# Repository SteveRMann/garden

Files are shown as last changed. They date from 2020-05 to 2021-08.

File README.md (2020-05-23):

# GardenProject
This project is for the solar-powered Wemos D1 mini with a DS18B20 temperature sensor and a Capacitive Moisture sensor.

---------------
Here is a project by Nick Gammon that uses a supercap instead of a battery.
https://www.gammon.com.au/forum/?id=12821

---------------
The publish functions expect char[] types to be passed in rather than Strings.
You need to use the String.toCharArray() function to convert your strings to the necessary type.

char charBuf[50];
stringOne.toCharArray(charBuf, 50)
myString.toCharArray(buf, len)

----------------------
For future reference:
#include <IPAddress.h>
IPAddress ipAddress(192, 168, 0, 1);  

--------

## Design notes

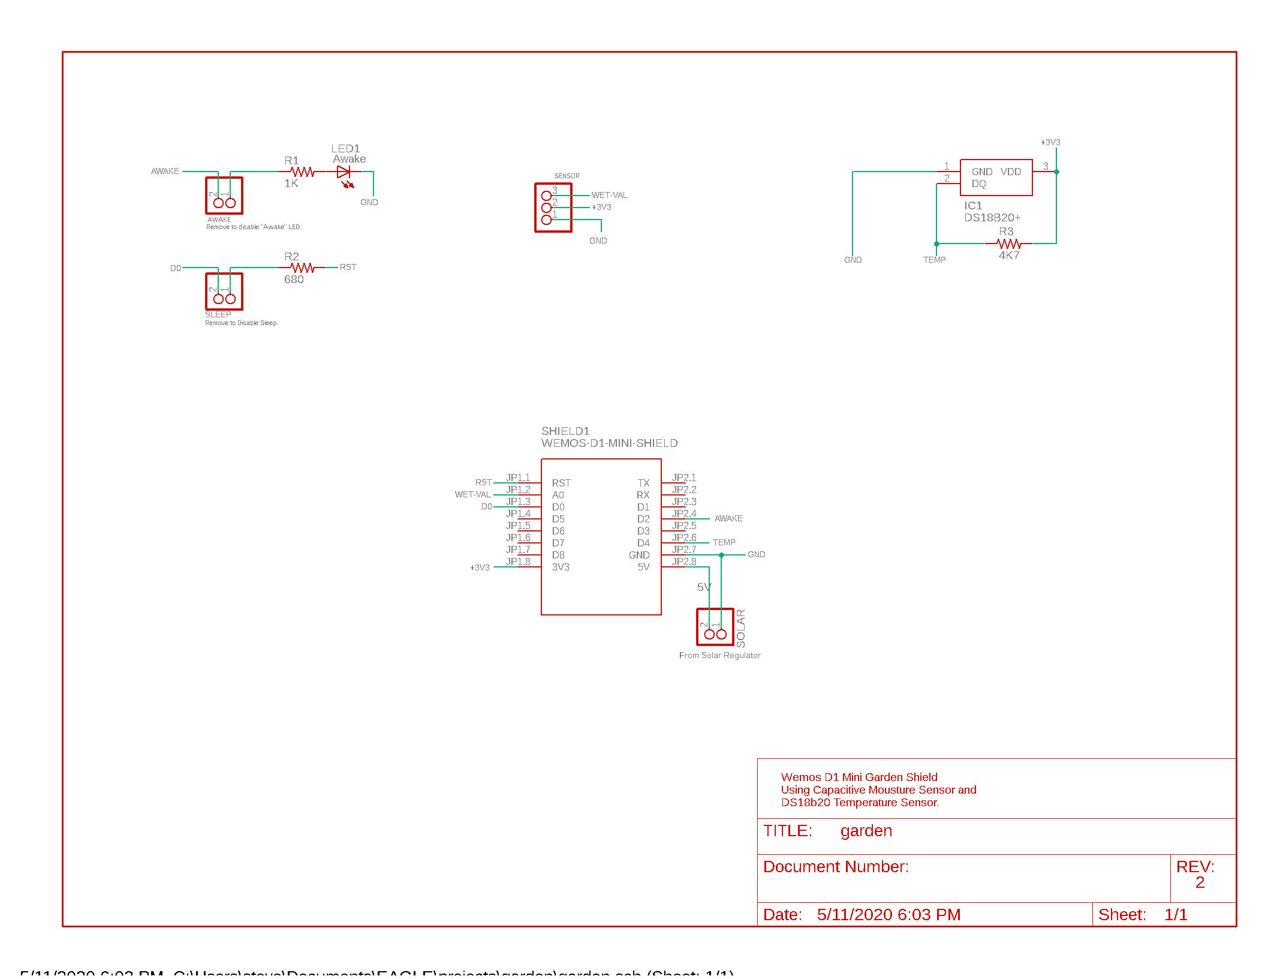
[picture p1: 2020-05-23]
Schematic.jpg

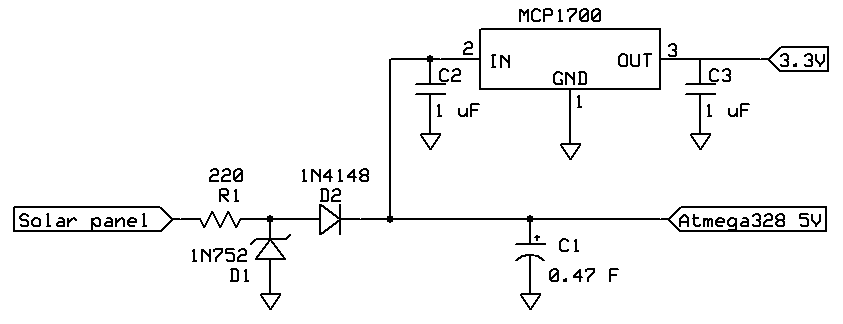
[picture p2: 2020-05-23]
Gammon Solar panel schematic.png

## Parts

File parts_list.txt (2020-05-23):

Partlist

Exported from garden.sch at 4/30/2020 11:53 AM

EAGLE Version 9.3.2 Copyright (c) 1988-2019 Autodesk, Inc.

Assembly variant: 

Part            Value                          Device               Package              Library        Sheet

AWAKE           Remove to disable "Awake" LED. PINHD-1X2            1X02                 DC_LOAD_AU     1
IC1             DS18B20+                       DS18B20+             TO-92                SamacSys_Parts 1
LED1            Awake                          LED3MM               LED3MM               adafruit       1
MOISTURE_SENSOR Moisture Sensor                PINHD-1X3/90         1X03/90              pinhead        1
R1              1K                             R-US_0207/9          0207/9               adafruit       1
R2              680                            R-US_0207/9          0207/9               adafruit       1
R3              4K7                            R-US_0207/9          0207/9               adafruit       1
SHIELD1         WEMOS-D1-MINI-SHIELD           WEMOS-D1-MINI-SHIELD WEMOS-D1-MINI-SHIELD diy-modules    1
SLEEP           Remove to Disable Sleep.       PINHD-1X2            1X02                 DC_LOAD_AU     1
SOLAR           From Solar Regulator           PINHD-1X2/90         1X02/90              DC_LOAD_AU     1
T1              2N2222                         2N2222               TO92-EBC-OVAL        adafruit       1

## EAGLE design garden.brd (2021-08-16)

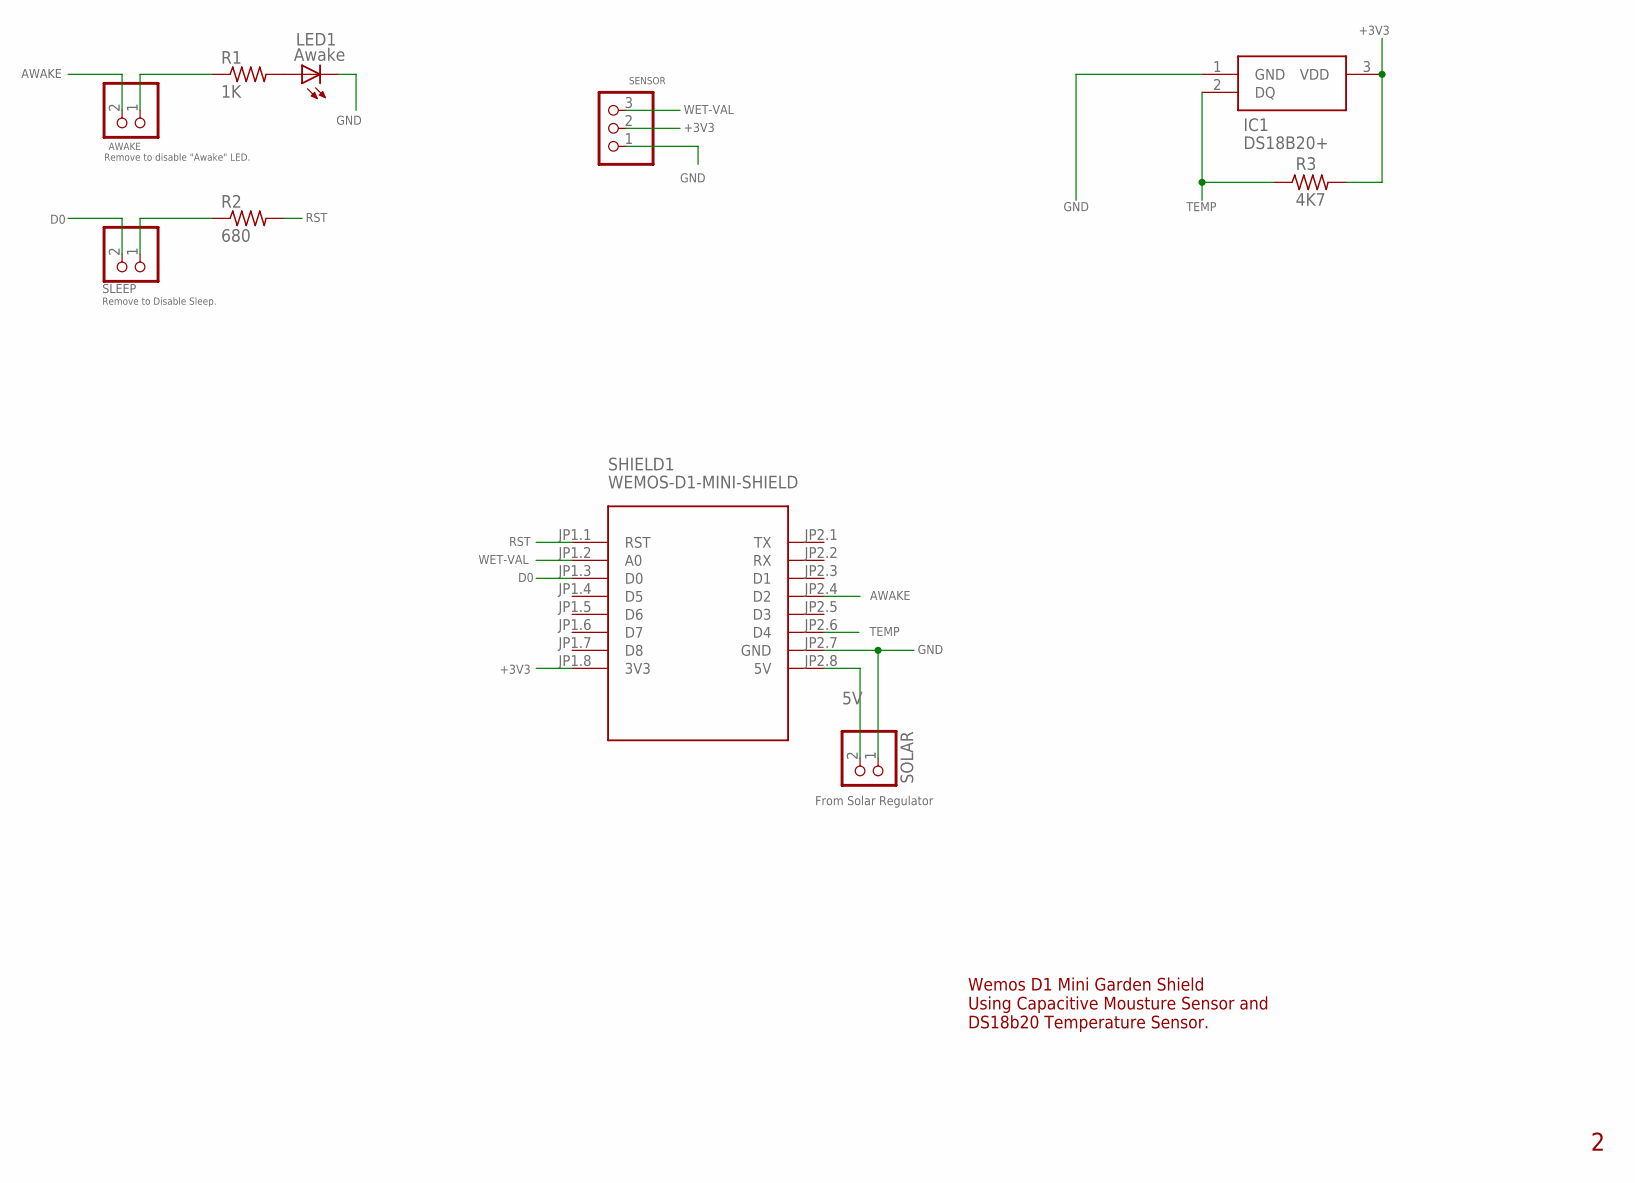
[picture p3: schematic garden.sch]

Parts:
AWAKE: Remove to disable "Awake" LED.; 1X02
IC1: DS18B20+; TO-92
LED1: Awake; LED3MM
R1: 1K; 0207/9
R2: 680; 0207/9
R3: 4K7; 0207/9
SENSOR: Moisture Sensor; 1X03/90
SHIELD1: WEMOS-D1-MINI-SHIELD
SLEEP: Remove to Disable Sleep.; 1X02
SOLAR: From Solar Regulator; 1X02/90

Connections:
5V: SHIELD1.JP2.8 (5V), SOLAR.2
+3V3: IC1.3 (VDD), R3.2, SENSOR.2, SHIELD1.JP1.8 (3V3)
AWAKE: AWAKE.2, SHIELD1.JP2.4 (D2)
D0: SHIELD1.JP1.3 (D0), SLEEP.2
GND: IC1.1 (GND), LED1.K (C), SENSOR.1, SHIELD1.JP2.7 (GND), SOLAR.1
unnamed: LED1.A, R1.2
unnamed: AWAKE.1, R1.1
unnamed: R2.1, SLEEP.1
RST: R2.2, SHIELD1.JP1.1 (RST)
TEMP: IC1.2 (DQ), R3.1, SHIELD1.JP2.6 (D4)
WET-VAL: SENSOR.3, SHIELD1.JP1.2 (A0)

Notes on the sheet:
Wemos D1 Mini Garden Shield Using Capacitive Mousture Sensor and DS18b20 Temperature Sensor.

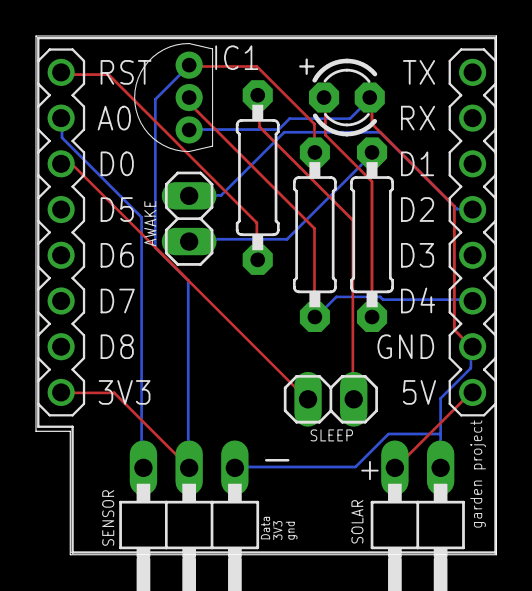
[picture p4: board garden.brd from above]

Board: 2 copper layers, 25.6 x 28.8 mm, 10 parts (0 on the bottom side), 11 nets.

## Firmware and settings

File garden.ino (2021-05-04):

#define sketchName "garden.ino, V2.1"

/*
   Forked from GardenProject
   Removed sleep.
   V2.1 5/4/21 Changed period to 5 minutes

   IDE:
     Board: Lolin(Wemos) D1 R2 & Mini

   Reference:
   http://www.esp8266learning.com/wemos-mini-ds18b20-temperature-sensor-example.php#codesyntax_3

*/


#include <OneWire.h>            // Driver for DS18X Temperature Sensors.
#include <ESP8266WiFi.h>        // Connect (and reconnect) an ESP8266 to the a WiFi network.
#include <PubSubClient.h>       // connect to a MQTT broker and publish/subscribe messages in topics.
#include <ArduinoOTA.h>
#include <ArduinoJson.h>

#ifndef Kaywinnet
#include "C:\Users\steve\Documents\Arduino\libraries\Kaywinnet\Kaywinnet.h"  // WiFi credentials
#endif


// ****************************** Globals  ******************************
#define NODENAME "garden"                         //Must be unique on the net.
const char *connectName =  NODENAME "garden";     //Must be unique on the network

//Probe Calibration
int dry = 457;                  //Dry sensor
int wet = 811;                  //Wet sensor


#define hostPrefix NODENAME     // For setupWiFi()
char macBuffer[24];             // Holds the last three digits of the MAC, in hex.


const char *statusTopic = NODENAME "/status";             //Sends the temperature, moisture, IP and RSSI in one payload.
const char *statusJsonTopic = NODENAME "/statusJson";
const char *cmdTopic = NODENAME "/cmd";                   //Sends a command string: readTime, temp correction
const int mqttPort = 1883;

const char *temperatureTopic = NODENAME "/temperature";
const char *wetTopic = NODENAME "/wet";
const char *rawTopic = NODENAME "/raw";
const char *ipTopic = NODENAME "/ip";
const char *rssiTopic = NODENAME "/rssi";
const char *sleepTopic = NODENAME "/sleep";


int sleepSeconds = 300;               //Seconds between readings
const int pubsubDelay = 20;           //ms between publishes
long rssi;                            //Used in the WiFi tab
float tCorrection = 0.0;              //Temperature correction.
char rssi_string[50];                 //RSSI in char array


OneWire  ds(D4);                      //Create an instance of the ds18b20 on pin D4


//Build an array of topics to subscribe to in mqttConnect()
static const char *mqttSubs[] = {
  cmdTopic
};



// Declare an object of class WiFiClient, which allows to establish a connection to a specific IP and port
// Declare an object of class PubSubClient, which receives as input of the constructor the previously defined WiFiClient.
WiFiClient GardenClient;                // The constructor MUST be unique on the network.
PubSubClient client(GardenClient);


#define DEBUG true  //set to true for debug output, false for no debug ouput
#define Serial if(DEBUG)Serial




// =================================== setup() ===================================
void setup(void)
{
  Serial.begin(115200);
  delay(10);
  Serial.println();
  Serial.println();
  Serial.println(sketchName);
  Serial.println();
  Serial.print(F("statusTopic= "));
  Serial.println(statusTopic);
  Serial.print(F("statusJsonTopic= "));
  Serial.println(statusJsonTopic);

  Serial.println();


  pinMode(D2, OUTPUT);
  digitalWrite(D2, HIGH);          // Turn on LED- We're awake.

  setup_wifi();
  start_OTA();


  // Call the PubSubClent setServer method, passing the broker address and the port.
  client.setServer(MQTT_SERVER, MQTT_PORT);
  mqttConnect();
  client.setCallback(callback);

}


// ==================================== loop() ====================================
void loop(void) {
  client.loop();                      //Check for MQTT messages
  ArduinoOTA.handle();                //check for OTA commands
  ArduinoOTA.onEnd([]() {
    Serial.println("\nUpload Ended");
  });

  mqttConnect();                        //Make sure we're still connected.
  
  Serial.println(F("\n----------"));    // Flag the top of the loop for debugging

  String rssiTemp;                                              //RSSI in String
  rssiTemp = String(rssi);                                      //convert the rssi to a String
  rssiTemp.toCharArray(rssi_string, rssiTemp.length() + 1);     //packaging up the data to publish to mqtt whoa...

  float fahrenheit = readDS();
  Serial.print(F("temperatureRaw= "));
  Serial.println(fahrenheit);
  Serial.print(F("tCorrection= "));
  Serial.print(tCorrection);
  fahrenheit = fahrenheit + tCorrection;

  int moistureVal = analogRead(0);                              //Read the moisture sensor
  Serial.print(F("\nraw= "));
  Serial.println(moistureVal);
  int moistureValPct = map(moistureVal, wet, dry, 100, 0);
  Serial.print(F("mapped= "));
  Serial.print(moistureValPct);
  Serial.println(F(" % "));


  String temperatureString = String(fahrenheit).c_str();
  String moistureRawString = String(moistureVal).c_str();
  String moisturePctString = String(moistureValPct).c_str();


  // Send data to statusTopic
  String status = temperatureString + ", " +
                  moisturePctString + ", " +
                  moistureRawString + ", " +
                  WiFi.localIP().toString() + ", " +
                  rssi_string + ", " +
                  String(sleepSeconds);


  Serial.print(F("status = \""));
  Serial.println(F("Temp, moistureRaw, moisture%, IP, rssi, sleep"));
  Serial.print(F("status = \""));
  Serial.print(status);
  Serial.println(F("\""));                                                 // Cloing quote.


  //The maximum MQTT message size, including header, is 128 bytes by default in PubSubClient.h,and
  //20 bytes are consumed in the header, so 108 characters is the limit.
  StaticJsonDocument<240> doc;          //Allocate the JSON document
  // Add values in the document
  doc["temp"] = temperatureString;
  doc["wet"] = moisturePctString;
  doc["raw"] = moistureRawString;
  doc["ip"] = WiFi.localIP().toString();
  doc["rssi"] = rssi_string;
  doc["sleep"] = String(sleepSeconds);


  String statusJson;
  serializeJson(doc, statusJson);       //Prints a JSON String to the buffer

  /*
    Serial.print(F("statusJson= "));      //Debug, to make sure the JSON string is good.
    Serial.println(statusJson);
    Serial.print(F("statusJson.length= "));
    Serial.println(statusJson.length());

    int e = client.publish(statusJsonTopic, (char*) statusJson.c_str());     // Publish the JSON string
    delay(pubsubDelay);                                                      // Publish never completes without a delay
    Serial.print(F("e= "));
    Serial.println(e);
  */

  int e = client.publish(statusTopic, (char*) status.c_str());  // Publish all data
  delay(pubsubDelay);                                           // Publish never completes without a delay
  if (!e) {
    Serial.print(F("Publish to topic: '"));
    Serial.print(statusTopic);
    Serial.println(F("' failed"));
    ESP.restart();
  }



  // Send individual topics because Home Assistant doesn't deal well with JSON strings.
  client.publish(temperatureTopic, (char*) temperatureString.c_str());
  delay(pubsubDelay);
  client.publish(wetTopic, (char*) moisturePctString.c_str());
  delay(pubsubDelay);
  client.publish(rawTopic, (char*) moistureRawString.c_str());
  delay(pubsubDelay);
  client.publish(ipTopic, (char*) WiFi.localIP().toString().c_str());
  delay(pubsubDelay);
  client.publish(rssiTopic, rssi_string);
  delay(pubsubDelay);
  client.publish(sleepTopic, (char*) String(sleepSeconds).c_str());
  delay(pubsubDelay);




  delay(sleepSeconds * 1000);       //Time between readings in ms
}

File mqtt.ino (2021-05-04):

// ================================== mqttConnect() =================================
// boolean connect(const char* id, const char* willTopic, uint8_t willQos, boolean willRetain, const char* willMessage);

void mqttConnect() {
  while (!client.connected()) {
    Serial.print(F("MQTT connection..."));
    if (client.connect(connectName)) {
      Serial.println(F("connected"));
    } else {
      Serial.print(F("failed, rc="));
      Serial.print(client.state());
      Serial.println(F("- trying again in 5-seconds."));
      delay(5000);
    }



    char subTopic[40];
    byte numberOfSubs = (sizeof(mqttSubs) / sizeof(mqttSubs[0]));
    Serial.print(numberOfSubs);
    Serial.println(F(" subscriptions: "));
    for (int i = 0 ; i < numberOfSubs; i++) {
      strcpy(subTopic, mqttSubs[i]);
      Serial.print(F("Subscribing to "));
      Serial.println(subTopic);
      client.subscribe(subTopic);
      delay(pubsubDelay);
    }
  }
}



// **********************************  mqtt callback *************************************
// This function is executed when some device publishes a message to a topic that this ESP8266 is subscribed to.
//
void callback(String topic, byte * message, unsigned int length) {

  Serial.println();
  Serial.print(F("Message arrived on topic: "));
  Serial.println(topic);


  // Convert the character array to a string
  String messageString;
  for (unsigned int i = 0; i < length; i++) {
    messageString += (char)message[i];
  }
  messageString.trim();
  messageString.toUpperCase();          //Make the string upper-case


  Serial.print("messageString: ");
  Serial.print(messageString);
  Serial.println();



  if (topic == cmdTopic) {
    char buf[24];
    strcpy(buf, messageString.c_str());

    // Tokenize
    char *tmpbuf;
    tmpbuf = strtok(buf, ",");
    sleepSeconds = atoi(tmpbuf);                       //sleepSeconds
    Serial.print(F("New readTime= "));
    Serial.print(sleepSeconds);
    Serial.println(F(" seconds"));

    tmpbuf = strtok(NULL, ",");
    tCorrection = atoi(tmpbuf);                        //tCorrection
    Serial.print(F("New Temperature Correction= "));
    Serial.print(tCorrection);
    Serial.println(F(" degrees"));

  }
} //callback

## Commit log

2020-05-23 Forked from GardenProject.ino
    [garden.sch]
2020-05-25 Add files via upload
    Added Arduino.h to publish data as a JSON string.
2020-05-25 Add files via upload
    -- Version 2.0 --
    5/25/20 - Added separate topics for each publish item. Home Assistant doesn't handle JSON strings well.
    [garden.ino]
2020-10-27 Added schematic of the Moisture Probe
    [Moisture_Probe.sch]
2021-08-16 Added .brd file
    [garden.brd]
2022-04-24 Added micro USB
    [garden.sch]

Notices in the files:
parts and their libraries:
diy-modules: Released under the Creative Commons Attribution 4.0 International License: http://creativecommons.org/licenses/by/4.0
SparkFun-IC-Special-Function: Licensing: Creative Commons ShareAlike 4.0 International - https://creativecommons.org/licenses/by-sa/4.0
